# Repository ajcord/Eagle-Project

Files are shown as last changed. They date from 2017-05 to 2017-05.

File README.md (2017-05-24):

# Eagle Project

I've been asked for the plans to my Eagle Scout Project many times, so I decided to just put them up on GitHub instead. Hopefully they are useful to anyone building their own firefighter training device.

Note that this is essentially a snapshot of how the project existed at its completion in 2012. I haven't tried to keep everything up to date, so your mileage may vary.

There are also a couple of YouTube videos for the project [here](https://www.youtube.com/playlist?list=PLlO3h9nk0MbyEmixgNUvEjmmrnmELnX12). Also, there are photos in the [images](https://github.com/ajcord/Eagle-Project/tree/master/images/) folder.

## Details

I wrote the instructions before I actually built the project, so they leave out some parts that I added later like the access holes in the bottom corners of the main wall and the foothold braces underneath the inner parts of the footholds (I will explain this below). They are also rather hard to follow at times. You should use them only as guidelines. My recommendation is to double check all of the measurements before you cut to ensure they make sense. The better you know the project, the less chance that you will make a mistake. That is why I recommend looking at the model in detail.

[Changes.pdf](https://github.com/ajcord/Eagle-Project/blob/master/instructions/Changes.pdf) explains most of the changes I made. [The model](https://github.com/ajcord/Eagle-Project/blob/master/model/Design_finished.skp) should include all of those changes as well (but with measurements). Where the instructions and the model differ, use the model. Also, SketchUp has a very useful tape measure tool that you can use to measure out anything on the model that you need. Feel free to move the plywood away from the main wall in the model so you can see what's inside. I also have a picture of the inside of the wall below.

These are the steps of the instructions that are not entirely valid:
* Step 4 is also where you probably should add the two extra support studs that I mention in the Changes attachment. They should extend from just above the top set of footholds to 1-1/2" below the bottom of the window. They should be attached to the inside of the two inner studs to provide support for the sill plate. See the model or the picture below if you need to see what I'm talking about.
* Main wall, steps 1 and 2: I forgot the 2x4 at the bottom of the wall. Adjust the measurements accordingly, and use the extra 4' 2x4 from step 1 to put on the bottom in step 2.
* Main wall, step 4: You should make the window slightly taller to take into account the height of the maple sill plate. In my case, that would mean it needs to be 2' 10-1/4" instead of 2' 9-1/2" because I think I used 3/4" maple. If you don't use the same thickness for your sill plate, you can just make the window spacer blocks shorter. Either way works.
* Main wall, step 7: I must have forgotten to include this in the instructions! This is when you attach the middle stud to the plywood. Put it between the middle footholds. It should reach just below the 2x4 under the window. This is also when you attach the foothold steps. See the note below for tips on how to attach them.
* Main wall, step 9: I didn't use the large sill plate. You can scratch that from the instructions (but you still should use the small sill plate).
* Extras, steps 1-3: I ended up just screwing the whole box together rather than bolting it. That means that one of the two plywood pieces will need to be shorter so that it just covers the 2x4s with no overhang. Then, simply screw it to the 2x4s. To attach this to the main wall in the future, you will need to screw it to the first set of window spacer blocks.
* Extras, step 5: I didn't plan this correctly. I ended up deciding to have only one set of window spacer blocks be bolted to the wall. The bolt holes are countersunk. The most common use case of the wall is with one set of spacers. If more are necessary, they can be screwed in as needed to the first set of spacers. When the first set of spacers is too full of holes, you can just cut another 2x4 down to size to replace it.

Note: When attaching the small 2x4 steps in the footholds, you will not be able to attach them directly unless you screw them in at an angle. I recommend taking two small scrap 2x4s (of which you should have plenty by the time you've cut 2x4s for everything else) and attaching them to the step in an upside-down U like this:

```
______
|    |
```

That way you will be able to screw those bottom parts to the wall studs instead of the steps themselves. Then, for added support, you can screw the steps into the studs diagonally and to the plywood.

Here is a picture of the inside of the wall for reference. Notice the two support studs below the window.

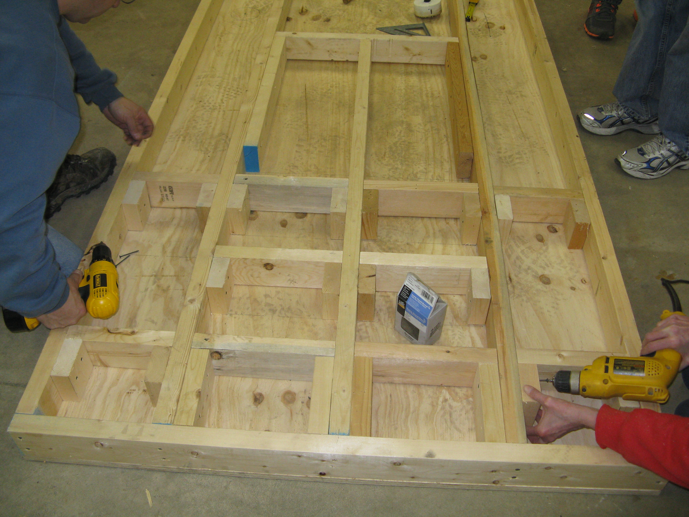
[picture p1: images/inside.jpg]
Inside of the wall


My final cost was $580.28, but a few of my materials were donated. However, those are probably offset by the cost of some of the materials I didn't use (like paint thinner to clean the paintbrushes and the return shipping cost on the wrong size of lag screws that I ordered online).
I've look through this parts list and updated it with what I think is the correct information. Some of the parts changed from planning to construction, but I think this is accurate.

### Materials
* 4 - 4' x 8' x 3/4" AC plywood. One of these needs to be cut down to 3' x 8'. I just had the lumber company do this because I didn't have a big enough table saw. However you want to do it is fine, just as long as you keep the 1' x 8' section for the sill riser block.
* 2 - 4' x 8' x 1/2" AC plywood
* 36 - 2x4 x 8' (36 is the minimum. You may want more in case you make a wrong cut.)
* 2 - 2x6 x 8'
* 1 - 4x4 x 10' (I used treated wood, if it matters.)
* 1 - 5" x 24" x 3/4" maple board (You could substitute any hard wood. I used maple because I already had some scraps. Also, the height can differ if you already have some scraps available. You will need to adjust step 4 of the main wall depending on the height you use.)
* 22 - 3/8" x 3-1/2" hex bolts (This might have been 24. I can't remember for sure. You might want to get 24 just in case.)
* 2 - 3/8" x 7" hex bolts
* 30 - 1/2" x 5" lag screws
* 30 - 1/2" washers for the lag screws
* 250 - 2-1/2" deck screws
* 48 - 3/8" flat washers (If it's 24 hex bolts above, then this needs to be 52.)
* 24 - 3/8" wing nuts (If it's 24 hex bolts above, then this needs to be 26.)
* Dust masks (recommended if power sanding)
* Ear plugs
* 3 quarts - wood varnish (this was for 2 layers)
* 1 - 3/8" x 3.7" x 4" square U bolt with hex nuts (or a different size/shape, as long as it can span the middle wall stud with some room to spare for the hex nuts. The one I got works well - I bought it at Ace Hardware.)
* A ladder, approximately 75" long if I remember correctly. This is optional but highly useful. As Dale mentioned, you can use the top section of an old extension ladder.
* Webbing or some other way to attach the ladder to the U-bolt.

### Tools
* Safety glasses - of course!
* Measuring tape
* Small square
* Center punch (recommended but not required)
* Adjustable wrenches
* Drill
* Router
* Table saw (if you are cutting the plywood sheets yourself)
* Miter saw
* Jigsaw
* Electric sander or sandpaper
* (Carpenter's) pencil
* Paintbrushes for varnishing

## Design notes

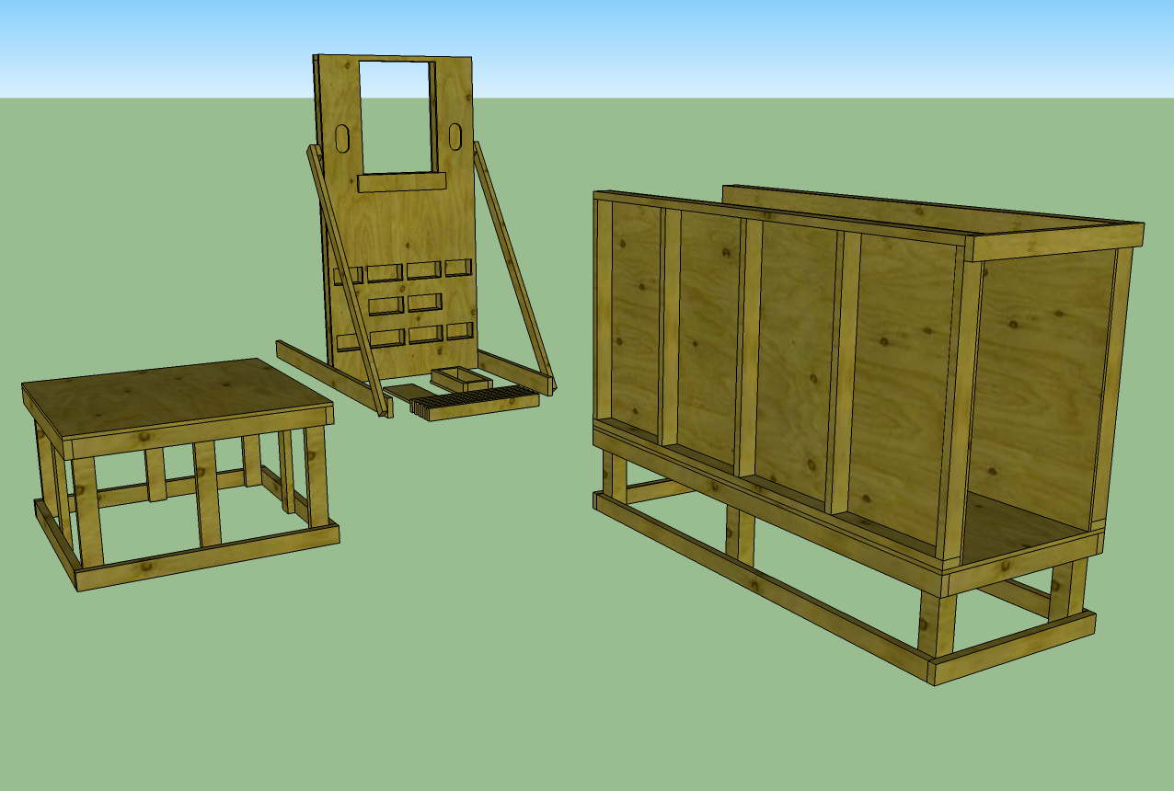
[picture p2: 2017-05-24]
model/Design_finished.png

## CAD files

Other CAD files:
instructions/Instructions.skp
model/Design_finished.skp

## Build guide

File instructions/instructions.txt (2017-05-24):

Volunteers (6):
*Volunteer 1: Adult with expertise in woodworking
*Volunteer 2: Adult with experience in wood cutting tools
*Volunteer 3: Adult with expertise in construction
*Volunteer 4: Youth with experience in construction tools
*Volunteer 5: Youth with experience in construction tools
*Volunteer 6: Youth with ability to measure accurately and precisely
------------------------------------------------------------------------
Denver attachment:
***TOP edges of walls are quarter rounded!***
    Deck board (1): 3' x 8' x 3/4"
    Wall boards (2): 4' x 8' x 1/2"
    Long braces (6): 2" x 4" x 8'
    Short braces (5): 2" x 4" x 2' 9"
    Base long braces (2): 2" x 4" x 7' 9"
    Base short braces (2): 2" x 4" x 3'
    Wall short braces (10): 2" x 4" x 3' 9"
    Top brace (1): 2" x 4" x 3'
    Deck supports (6): 4" x 4" x 1' 5-1/4"
*Volunteers 1 & 6: Cut (1) 4' x 8' x 3/4" board down to 3' wide using a table saw to make the deck board.
*Volunteers 2 & 6: Cut (3) 2x4s using a miter saw into a total of (5) 2' 9" short braces.
*Volunteers 1 & 6: Cut (1) 4x4, using a miter saw, into (6) 1' 5-1/4" deck supports.
*Volunteer 4: Attach (2) 2x4s to the edges of the underside of the deck board using deck screws.
*Volunteers 5 & 6: Attach 5 short braces to the underside of the deck using deck screws, perpendicular to the long braces, spaced equally 1' 10-1/8" apart.
*Volunteers 2 & 6: Cut (2) 2x4s, using a miter saw, into (2) 7' 8" base long braces, and cut (1) 2x4, using a miter saw, into (2) 3' base short braces.
*Volunteer 3: Attach the deck supports to the braces on the underside of the deck, using 2 lag bolts per support.
*Volunteer 3: Attach base long braces and base short braces to the base of the deck supports using deck screws.
Do the following steps twice (once for both walls):
    *Volunteer 4: Attach 2 long braces to a wall board using deck screws.
    *Volunteers 5 & 6: Attach 5 short braces to the wall board using deck screws, spaced equally 1' 10-1/8" apart.
*Volunteer 3: Attach both finished walls to the deck using hex bolts, with the braces facing outward.
*Volunteers 2 & 6: Cut a 3' top brace, using a miter saw, from the remainder of one of the short braces.
    *Volunteer 5: Attach top brace across the width of the opening to the top of both of the walls using hex bolts.
*Done with the Denver attachment!
------------------------------------------------------------------------
Main wall:
***ALL edges are quarter rounded!***
    Wall boards (2): 4' x 8' x 3/4"
    Long studs (4): 2" x 4" x 7' 10-1/2"
    Short stud (1): 2" x 4" x 5' 1"
    Frame top (1): 2" x 4" x 4'
    Base supports (2): 2" x 6" x 8'
    Angle braces (2): 2" x 4" x 7'
    Sill plates (2): 5" x 28" x 1" and 4" x 24" x 1"
*Volunteers 1 & 6: Cut (4) 2x4s to 7' 10-1/2", (1) 2x4 to 5' 1/2", and (1) 2x4 to 4' using a miter saw.
*Volunteers 3 & 6: Attach long studs to frame top using deck screws. Inner studs are 9" from inner edge of outer studs.
*Volunteer 5: Attach (1) wall board to the frame, one deck screw per corner.
*Volunteers 1 & 6: Trace window, tool-in-wall, and footholds on wall board.
    *Window: Stud-to-stud wide (2') x 2' 9-1/2" high (to bottom of frame top)
    *Tool-in-wall: 4" wide, 4" from side of window and side of wall board, 8" high, pill shaped, bottom of hole is 7-1/2" from bottom of window
    *Footholds: Stud-to-stud, 5" high, top of hole is 10" above bottom of previous row
*Volunteer 5: Remove wall board from frame.
*Volunteer 2: Drill in center of each marked out hole to prepare for jigsaw.
*Volunteer 1: Cut window, tool-in-wall, and footholds out from wall board using a jigsaw.
*Volunteer 5: Attach unused wall board to frame, one deck screw per corner.
*Volunteers 1 & 6: Trace window on wall board.
*Volunteer 5: Remove wall board from frame.
*Volunteer 2: Drill in center of wall board to prepare for jigsaw.
*Volunteer 1: Cut window out from wall board using a jigsaw.
*Volunteers 2 & 6: Cut (1) 2x4 into (4) 9" pieces using a miter saw.
    *Volunteer 5: Attach foothold steps & short stud to front wall board using deck screws, below each outer foothold so top of step is flush with bottom of foothold.
*Volunteers 2 & 6: Cut the remaining part of the previous 2x4 into (5) 11-1/4" pieces, and cut the remaining part of the top brace into (1) 11-1/4" piece, using a miter saw.
    *Volunteer 5: Attach as above to the remaining footholds
*Volunteer 4: Attach front and back wall boards to frame using deck screws.
*Volunteers 1 & 6: Cut (1) 5" x 28" x 1" and (1) 5" x 24" x 1" maple sill plate using a table saw.
*Volunteer 3: Attach small sill plate to window sill and large sill plate beneath window sill using deck screws.
*Volunteers 5 & 6: Attach (2) 2x6s to bottom of walls using hex bolts, 3' 9-1/2" from ends of 2x6s so wall is centered on 2x6s.
*Volunteers 2 & 6: Cut (2) 2x4s to 7' angle braces, with the bottom end at 45 degrees, using a miter saw.
    *Volunteer 2: Attach a 2"x4"x4" (approx.) piece of scrap wood to top end of both angle braces using deck screws.
    *Volunteer 5: Attach angled ends of angle braces to front ends of base supports using hex bolts, and attach other ends of angle braces to outer studs just below tool-in-wall holes using hex bolts.
*Pat yourself on the back - the main wall is done!
------------------------------------------------------------------------
Deck:
***ALL edges are quarter rounded!***
    Deck board (1): 4' x 4' x 3/4"
    Long braces (4): 2" x 4" x 4'
    Short braces (6): 2" x 4" x 3' 9"
    Deck supports (6): 2" x 4" x 2' 3-3/8"
*Volunteers 1 & 6: Cut (1) 4' x 8' x 3/4" board down to 4' long using a table saw to make the deck board.
*Volunteers 2 & 6: Cut (2) 2x4s in half using a miter saw to make (4) 4' long braces.
    *Volunteer 4: Attach 2 long braces to the underside of the deck using deck screws.
*Volunteers 2 & 6: Cut (3) 2x4s each into (2) 3' 9" short braces using a miter saw.
    *Volunteer 5: Attach 2 short braces to the underside of the deck using deck screws, perpendicular to the long braces.
    *Volunteers 5 & 6: Attach 2 short braces to the underside of the deck using deck screws, parallel to the long braces, equally spaced 1' 1-5/16" from the inner edges of the long braces.
*Volunteers 1 & 6: Cut (2) 2x4s each into 3 pieces, and cut 1 piece from remainder of middle stud of main wall, for a total of (8) 2' 3-3/8" deck supports, using a miter saw.
    *Volunteer 3: Volunteer 3: Attach deck supports using deck screws in the pattern:
        -------------
        ||    -    ||
        |           |
        ||         ||
        |           |
        ||    -    ||
        -------------
*Volunteer 4: Attach the other 2 long braces & 2 short braces to the bottom of the deck supports using deck screws.
*Done with the deck!
------------------------------------------------------------------------
Extras:
*Volunteers 1 & 6: From remainder of Denver attachment deck board, cut (2) 24" x 9-1/2" sill riser plates using a table saw.
*Volunteers 2 & 6: From remainder of any 2x4s, cut (2) 22" and (2) 6-1/2" sill riser boards using a miter saw.
    *Volunteer 4: Attach the 21" boards to the 24" sides of a sill riser plate using deck screws.
    *Volunteer 5: Attach the 5-1/2" boards parallel to the 9-1/2" sides of the sill riser plates using deck screws.
    *Volunteer 3: Attach the sill riser plates together using 2 hex bolts.
*Volunteers 1 & 6: Cut (3) 2x4s each into (2) 33-1/2" spacer blocks using a miter saw.
    *Volunteer 3: Attach to the inner sides of the window on the main wall using 2 hex bolts each.
        *Make sure screw holes are offset and spacer blocks are numbered to match up bolt holes.
*Go get some donuts because this project is complete!

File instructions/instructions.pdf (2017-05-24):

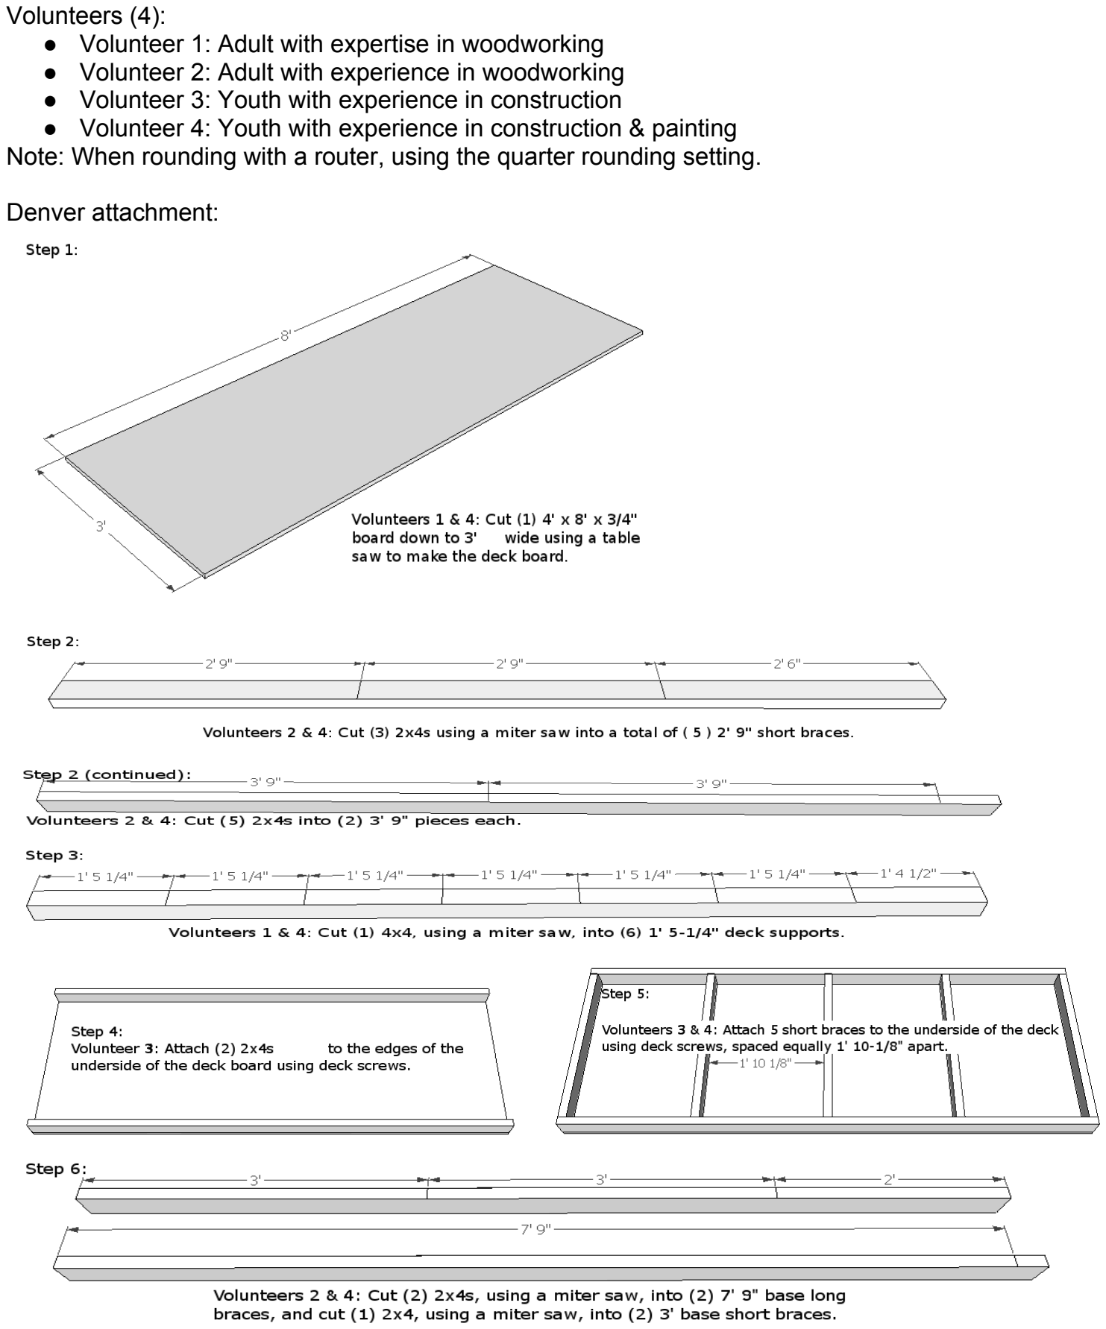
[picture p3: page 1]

Volunteers (4):
- Volunteer 1: Adult with expertise in woodworking
- Volunteer 2: Adult with experience in woodworking
- Volunteer 3: Youth with experience in construction
- Volunteer 4: Youth with experience in construction & painting Note: When rounding with a router, using the quarter rounding setting.

Denver attachment:

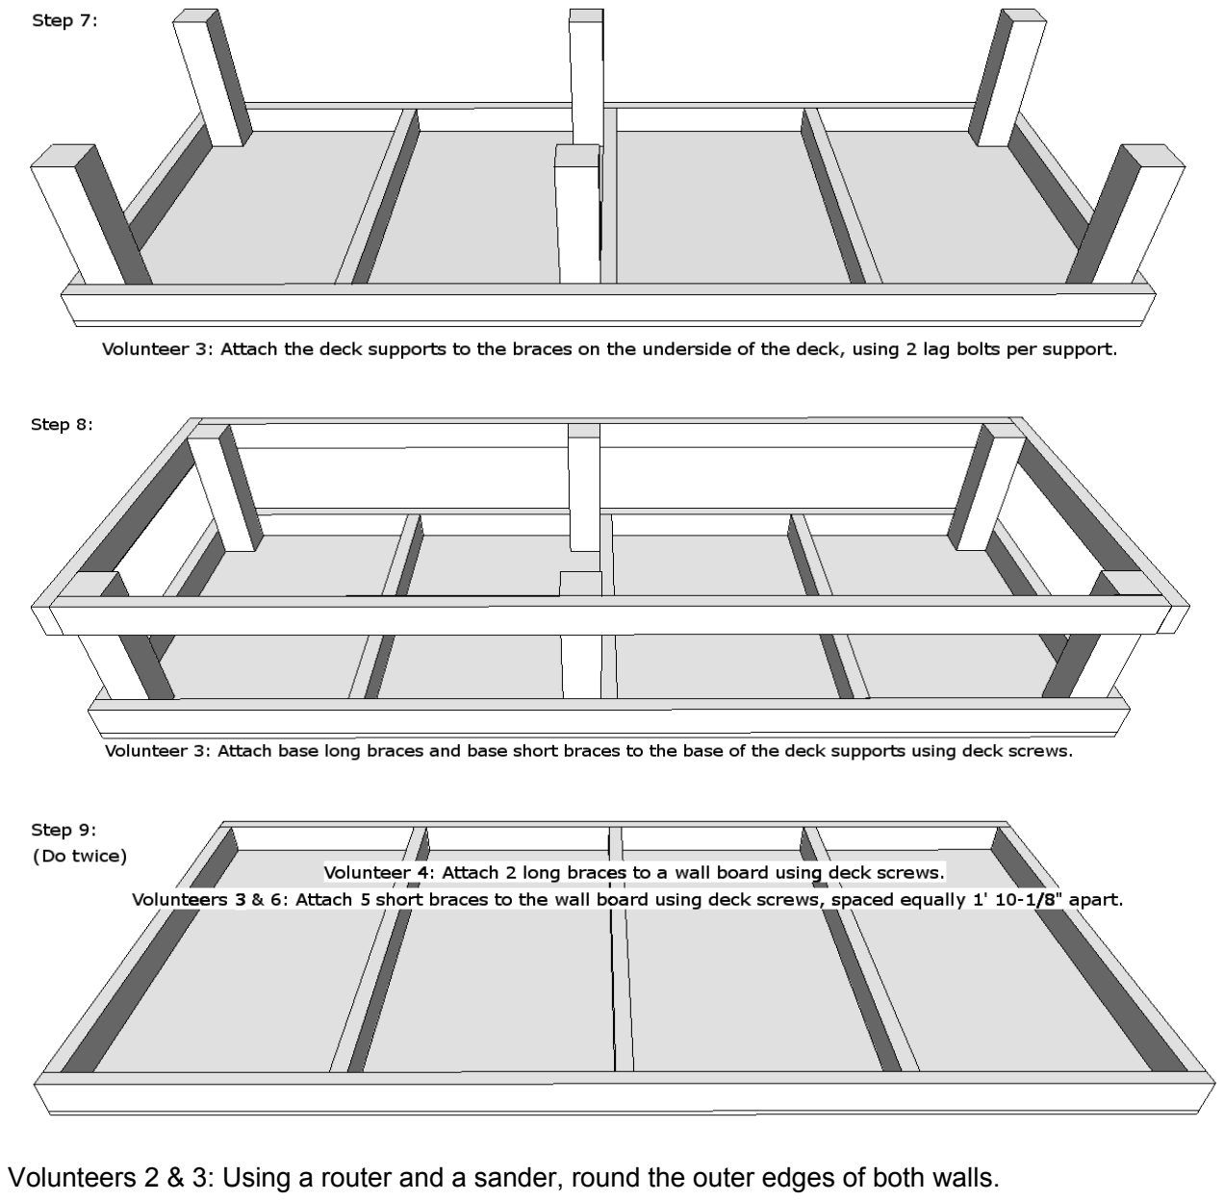
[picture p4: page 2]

Volunteers 2 & 3: Using a router and a sander, round the outer edges of both walls.

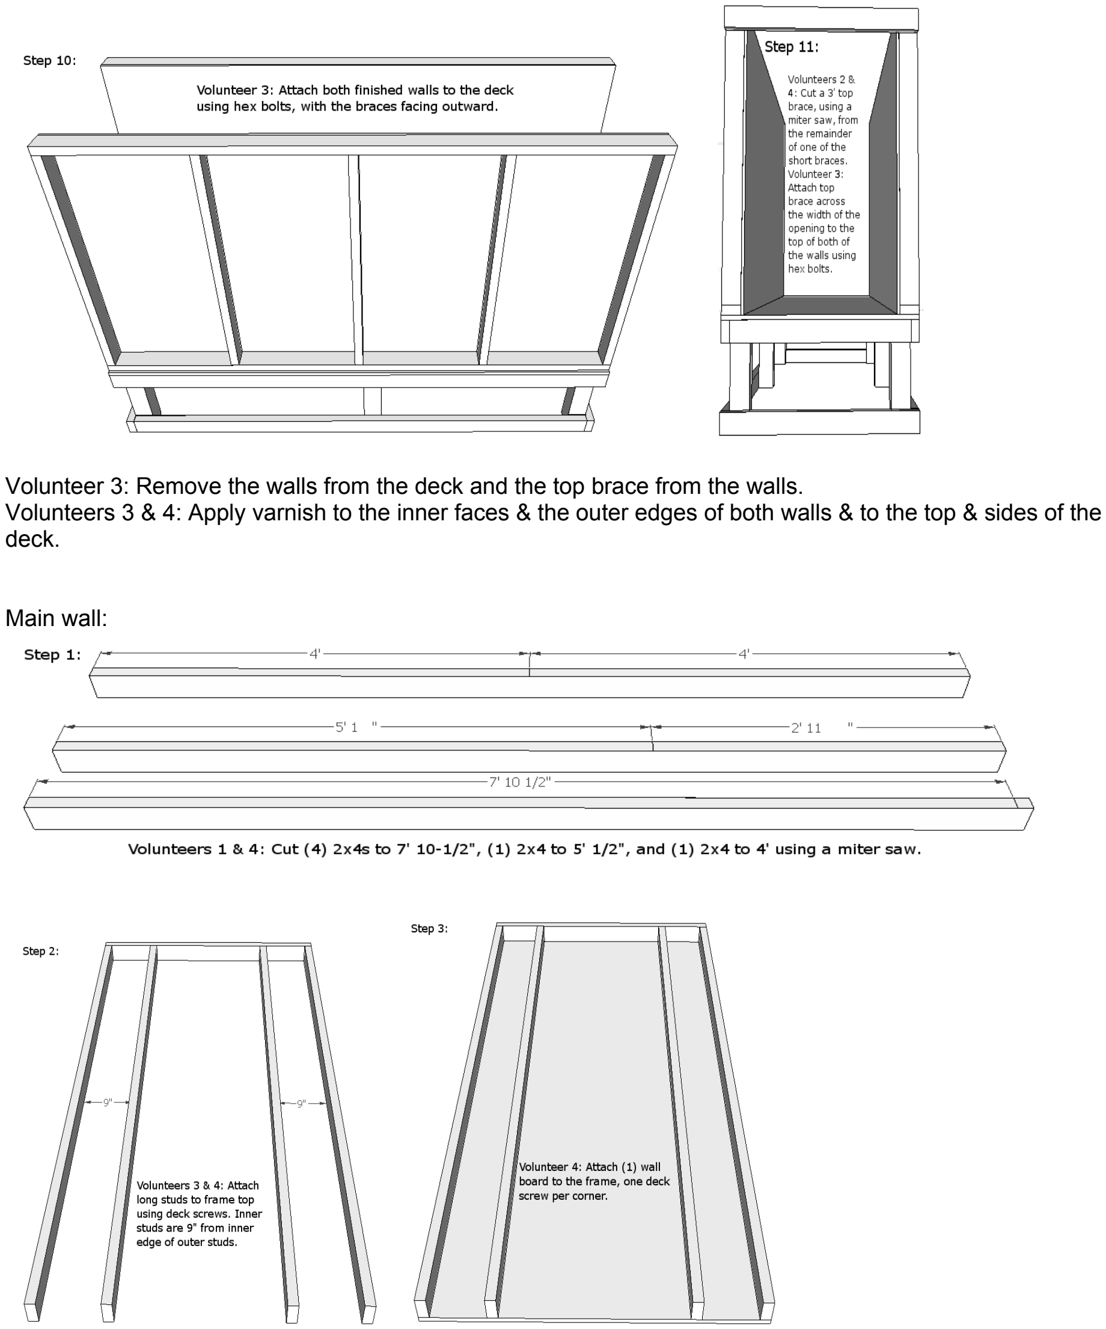
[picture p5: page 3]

Volunteer 3: Remove the walls from the deck and the top brace from the walls.
Volunteers 3 & 4: Apply varnish to the inner faces & the outer edges of both walls & to the top & sides of the deck.

Main wall:

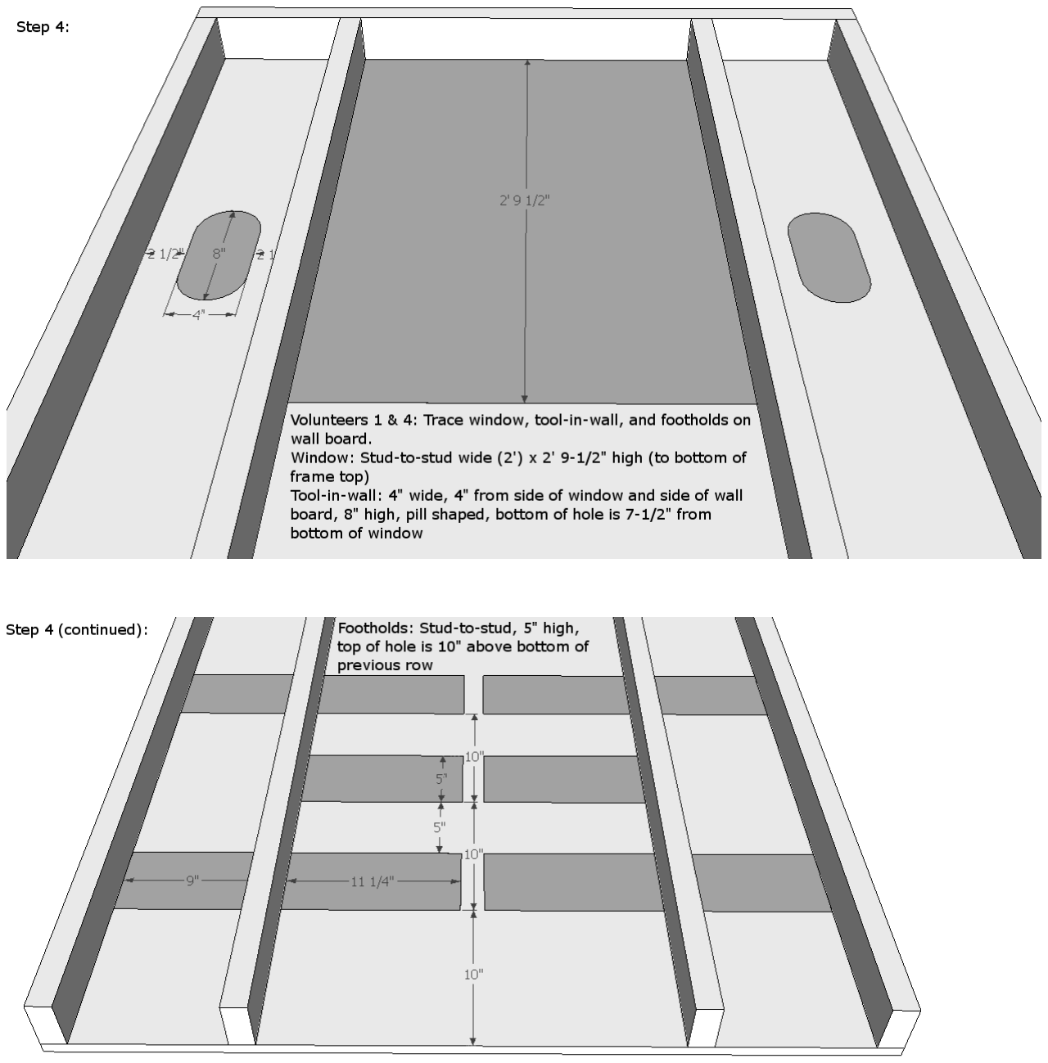
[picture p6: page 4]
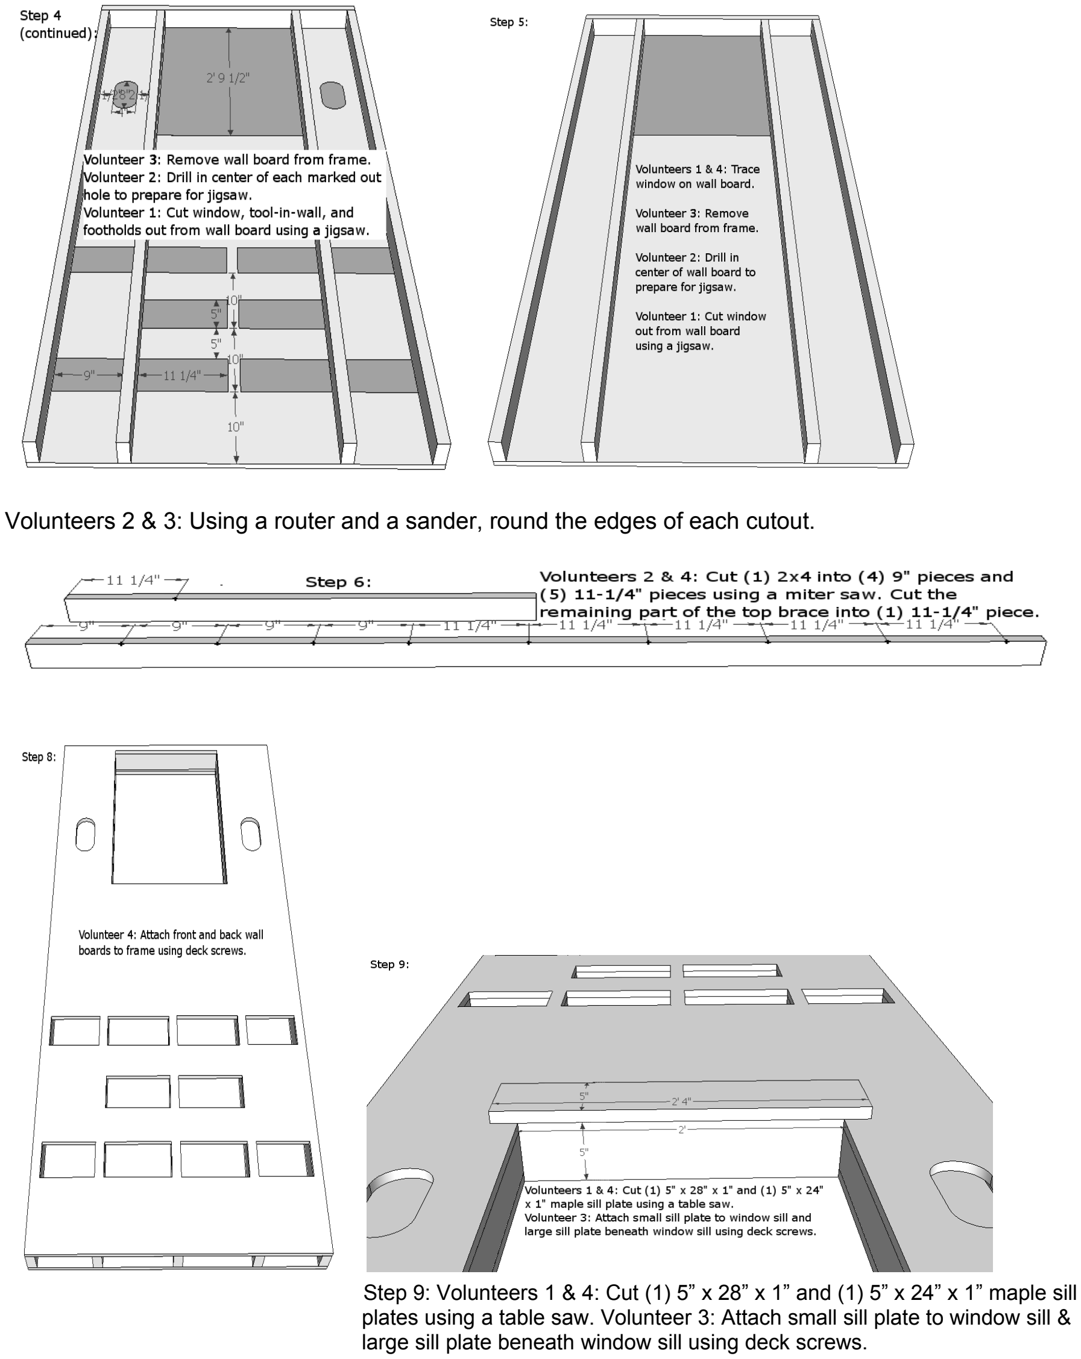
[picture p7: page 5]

Volunteers 2 & 3: Using a router and a sander, round the edges of each cutout.

Step 9: Volunteers 1 & 4: Cut (1) 5” x 28” x 1” and (1) 5” x 24” x 1” maple sill plates using a table saw. Volunteer 3: Attach small sill plate to window sill & large sill plate beneath window sill using deck screws.

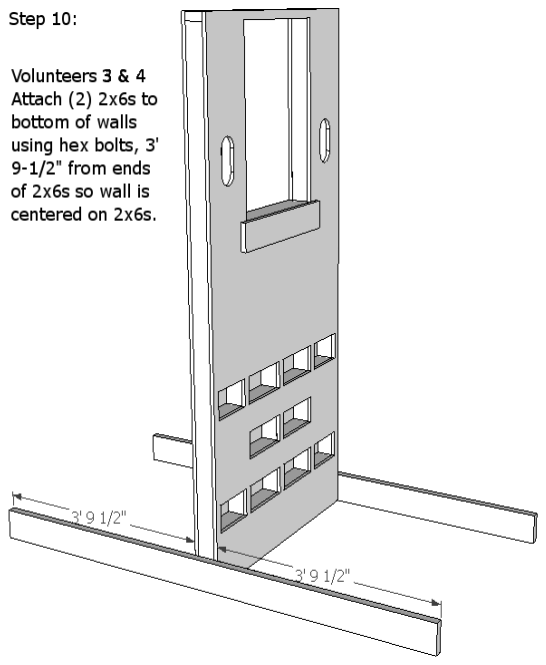
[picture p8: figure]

Volunteers 2 & 3: Using a router and a sander, round all remaining edges of the wall, the top edges of the base supports, and the angle braces.

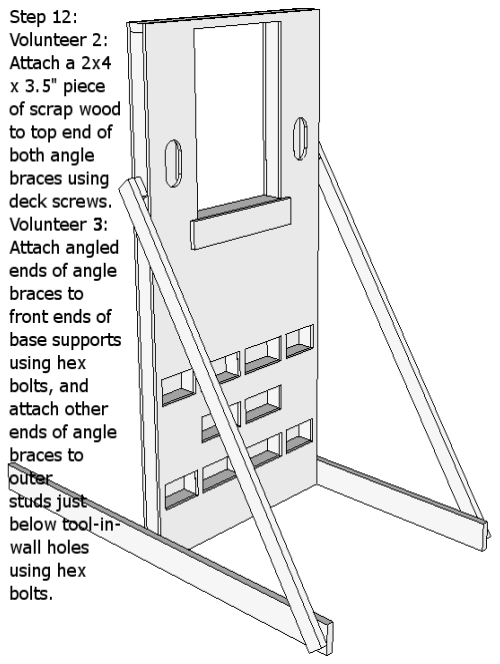
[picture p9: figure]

Volunteer 3: Remove all the braces from the wall and from each other. Volunteers 3 & 4: Apply varnish to all surfaces of the wall and to each brace.

Deck:

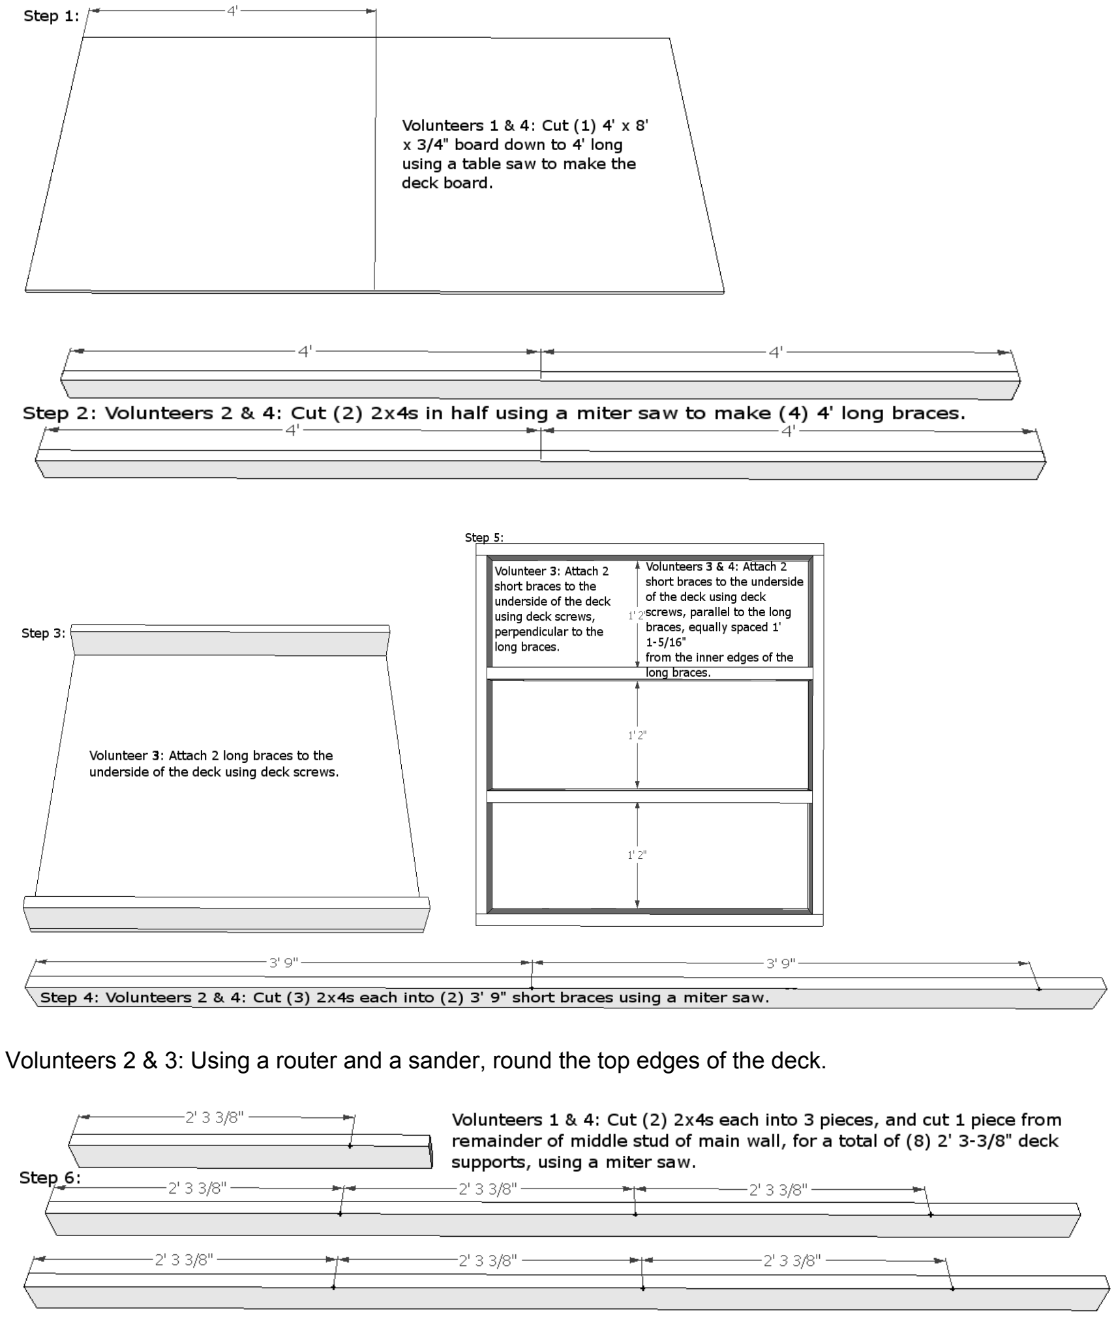
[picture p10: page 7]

Volunteers 2 & 3: Using a router and a sander, round the top edges of the deck.

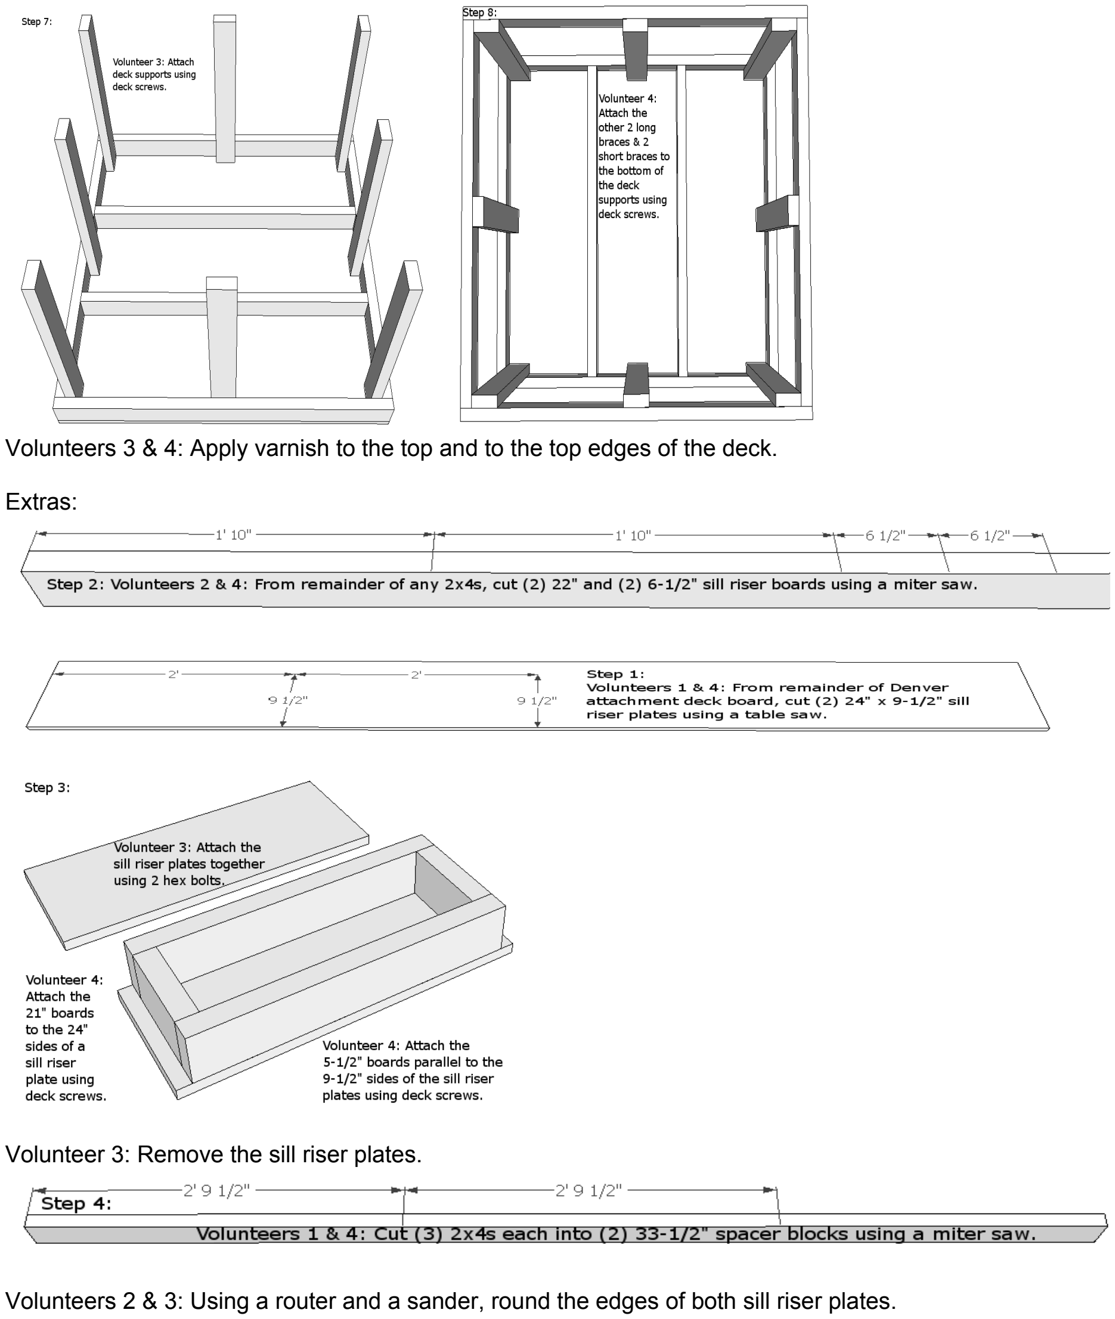
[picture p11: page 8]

Volunteers 3 & 4: Apply varnish to the top and to the top edges of the deck.

Extras:

Volunteer 3: Remove the sill riser plates.

Volunteers 2 & 3: Using a router and a sander, round the edges of both sill riser plates.

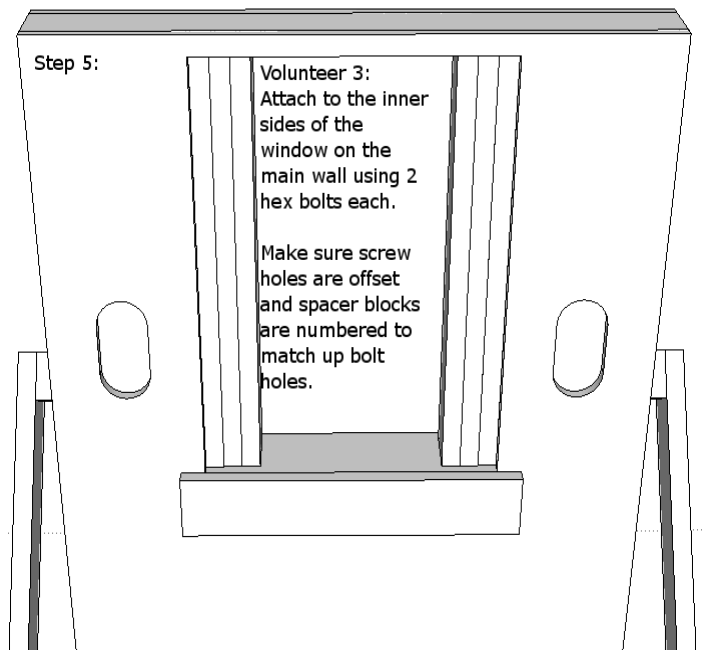
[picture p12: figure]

Volunteer 3: Remove the spacer blocks from the wall.

Volunteers 2 & 3: Using a router and a sander, round the long edges of the spacer blocks.

Volunteers 3 & 4: Apply varnish to each spacer block.

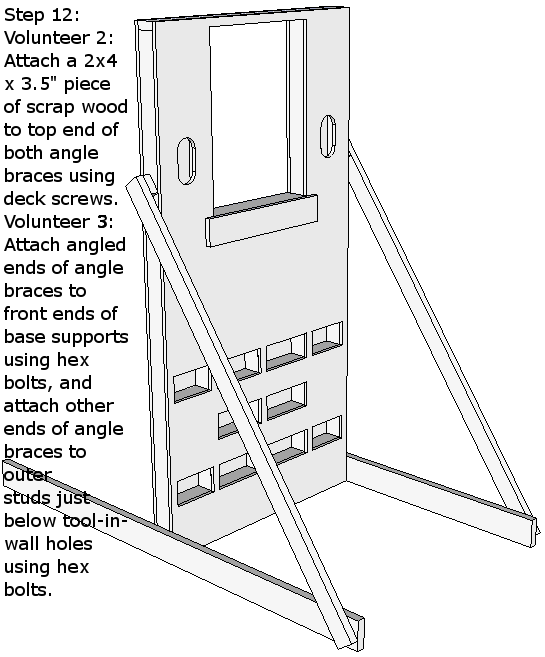
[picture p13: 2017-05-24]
instructions/Main wall/12.png

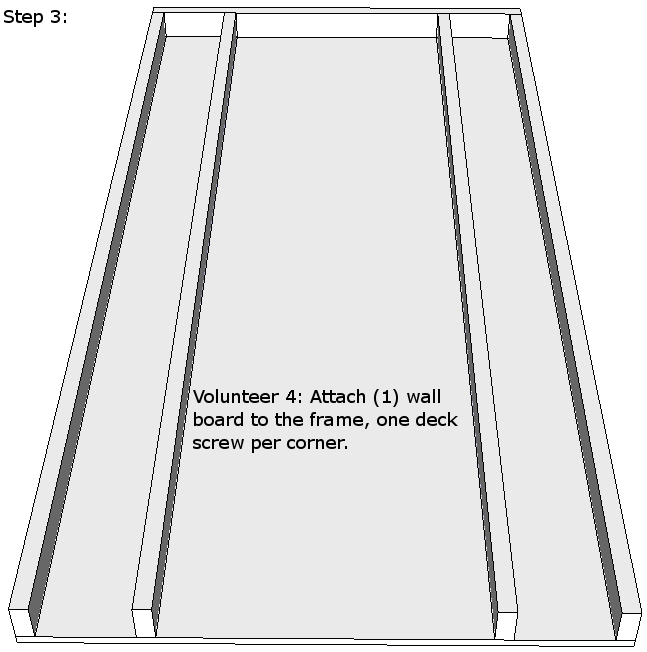
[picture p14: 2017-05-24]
instructions/Main wall/3.png

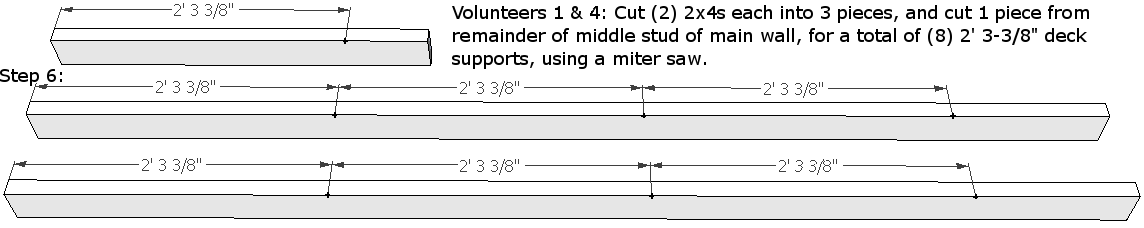
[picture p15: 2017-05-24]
instructions/Deck/6.png

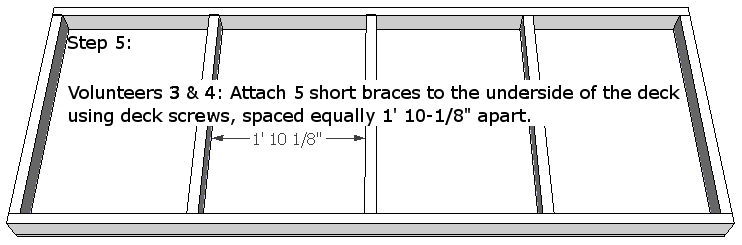
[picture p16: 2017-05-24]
instructions/Denver attachment/5.png

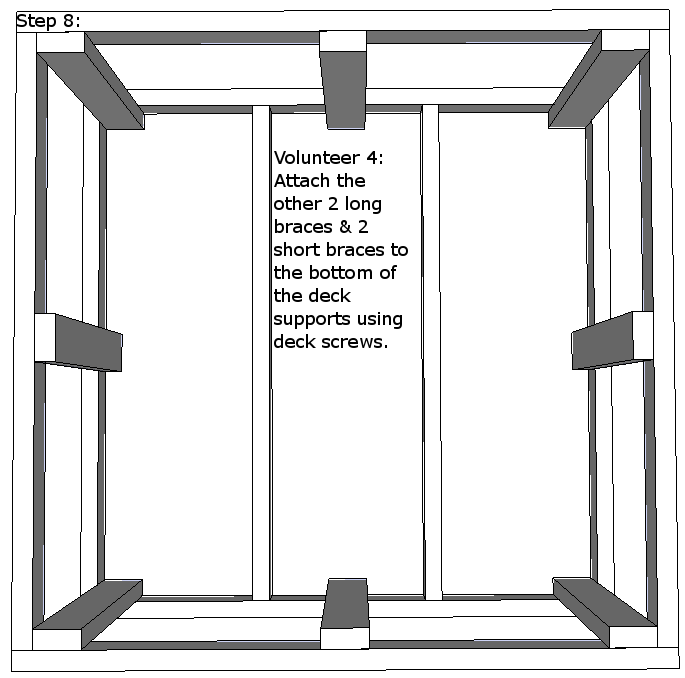
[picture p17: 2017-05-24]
instructions/Deck/8.png

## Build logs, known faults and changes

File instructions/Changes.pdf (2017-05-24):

I decided to make the sill riser block a single piece rather than the 2-piece "sandwich" design I had planned. The reasoning was that a solid piece would prevent protruding bolt heads and wing nuts from catching on the firefighters' gear. Using this design, the firefighters would screw the front plate to the window spacer blocks with deck screws.

The first alteration of the main wall was to add a 2x4 to the bottom of the wall in order to make the frame stronger and to aid in construction. Because of this, we had to drill access holes for the bolt that attaches the floor brace to the main wall. This should have been part of the plan to begin with. Another change we made was to add two extra support studs to the two interior studs for the purpose of supporting the sill, rather than add a fascia plate to the front of the wall to support the sill. In addition to the extra support studs, we added scrap 2x4 squares underneath the footholds to provide added support and to aid in construction. Due to the fact that the footholds are all in even lines, it would be almost impossible to attach them all to the studs and still provide enough support.

I spent a long period of time on the third day discussing with my aunt, uncle, and dad to come up with a solution to fasten the window spacer blocks to the inner window frame. We had come up with several possible solutions, some better than others (duct tape was up for discussion at one point), until we decided to allow the firefighters to make the final decision because they would be the ones assembling and using the wall. The firefighters later decided to bolt the first two spacer blocks and screw the rest in with deck screws.
